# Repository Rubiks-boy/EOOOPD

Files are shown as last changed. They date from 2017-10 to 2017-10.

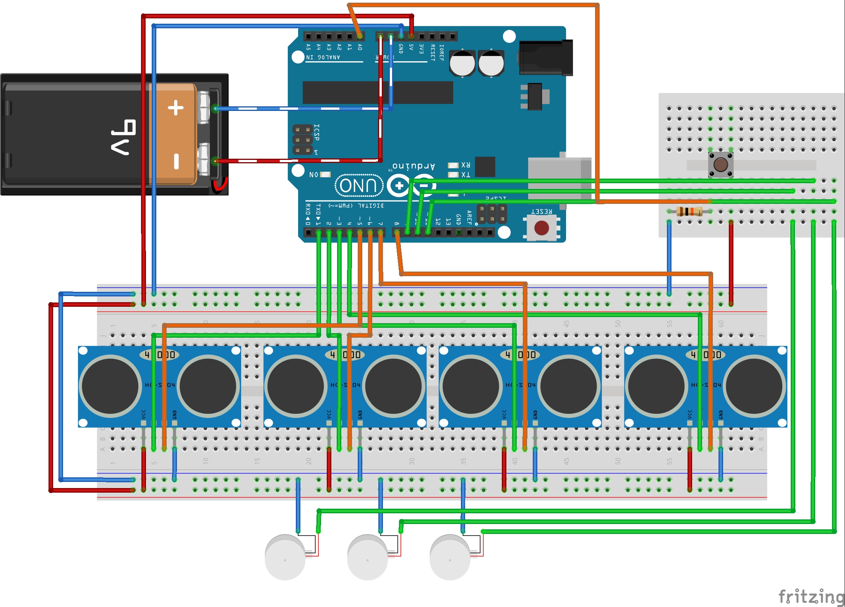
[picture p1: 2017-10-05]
Graphics/breadboard graphic.jpg

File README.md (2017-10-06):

# EOOOPD
Economical Optimal Optical Obstacle Proximity Detector - ISEF Project by Adam Walker &amp; Russell Ro

Embedded system attachment to a white cane; uses ultrasonic sensors on left and right of white cane to detect oncoming obstacles, then warns the user through haptic feedback on the handle via corresponding left and right vibration motors.

Abstract:

The white cane has helped the blind for centuries, but how can this basic invention be revolutionized using twenty-first century technologies at an affordable price? This project tackles the main problem with a white cane: the lack of sideways perception. Distance sensors were added to a standard white cane at angles both left and right, and user feedback is given through vibration sensors. The effectiveness of the sensors was tested by moving objects towards the individual at several velocities and at several angles (left and right). Tests were completed by recording the distance at which user reaction occurred. Our hypothesis was that those who are sight-impaired can sense and avoid objects approaching from increased angles, emulating peripheral vision. The experimental results support this hypothesis by showing that an increased peripheral perception can be achieved through intensifying vibration feedback based on the proximity of an object.

This project won first place in the engineering category at the Beal Bank USA Southern Nevada Regional Science & Engineering Fair at the University of Nevada, Las Vegas on March 15, 2017, qualifying the project for Intel's International Science and Engineering Fair in Los Angeles on May 14-19, 2017.

Adam Walker - adamwalker567123@gmail.com (Programming)<br />
Russell Ro - pr.russell.ro@gmail.com (3D Modeling)

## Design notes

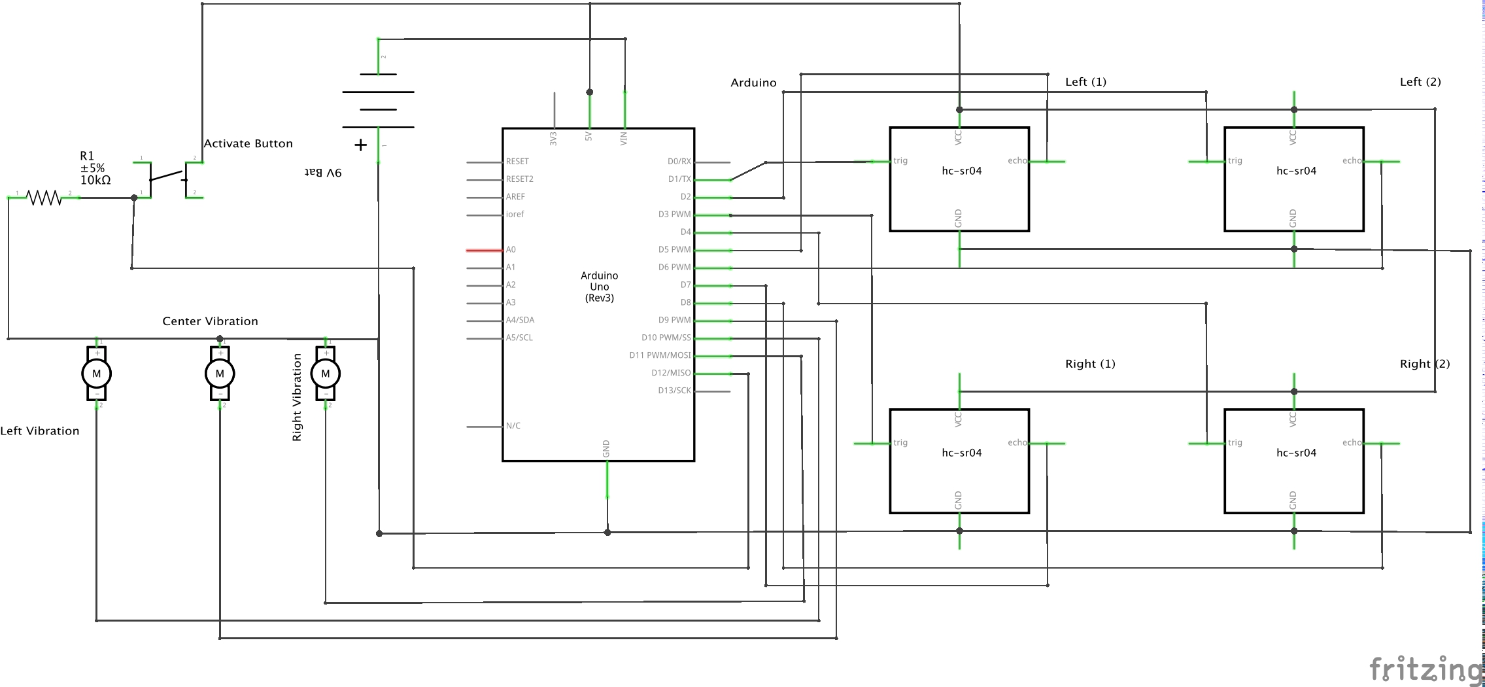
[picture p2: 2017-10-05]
Graphics/schematic.jpg

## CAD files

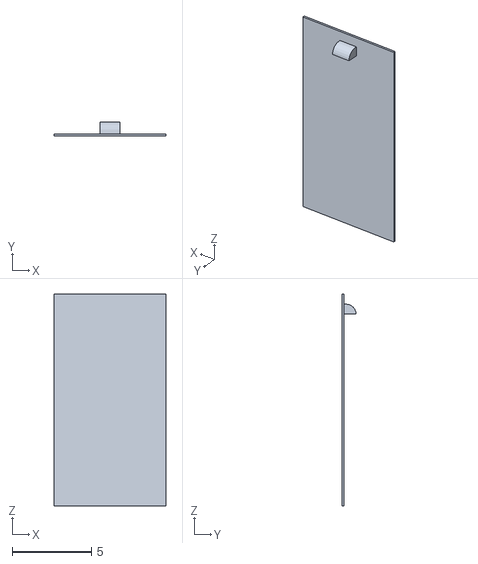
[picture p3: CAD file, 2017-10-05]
Finalized 3D Print Files/EOOOPD Lid V4.stl
7.03 x 0.89 x 13.3

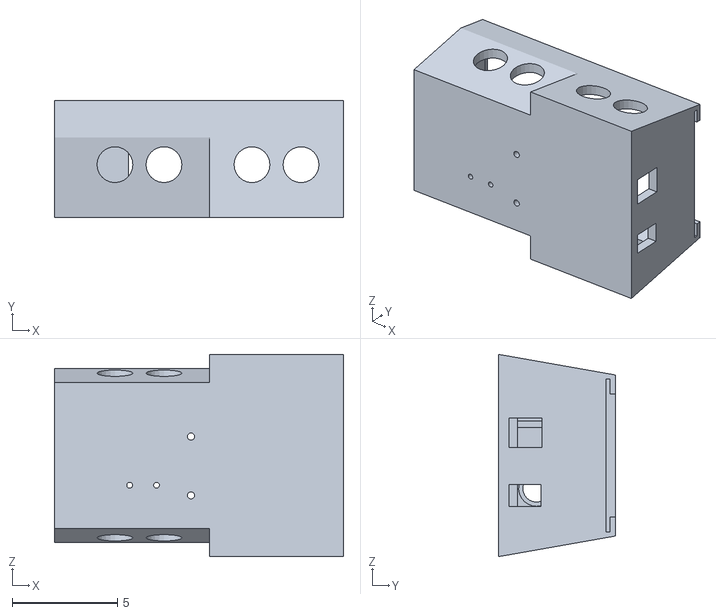
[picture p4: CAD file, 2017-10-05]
Finalized 3D Print Files/EOOOPD Casing V4.stl
13.7 x 5.54 x 9.59

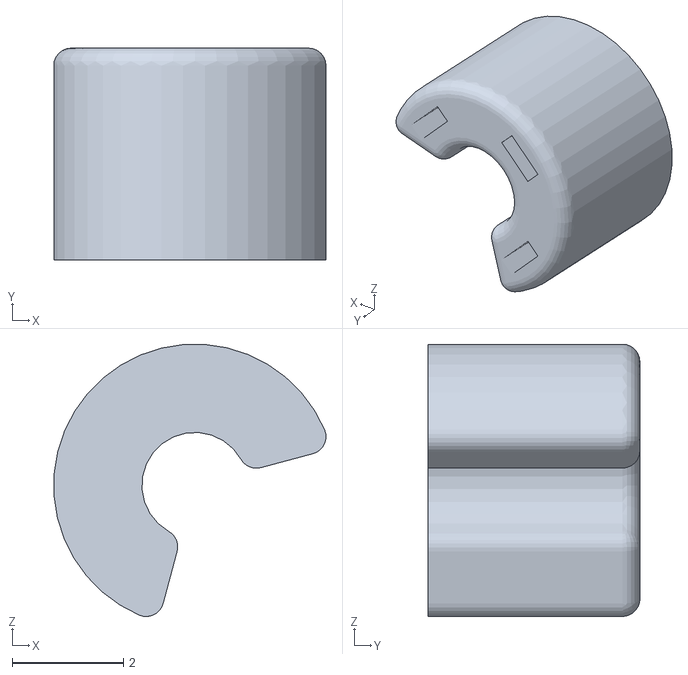
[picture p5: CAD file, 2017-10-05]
Finalized 3D Print Files/EOOOPD Vibration Encasement V3.stl
4.89 x 3.81 x 4.89

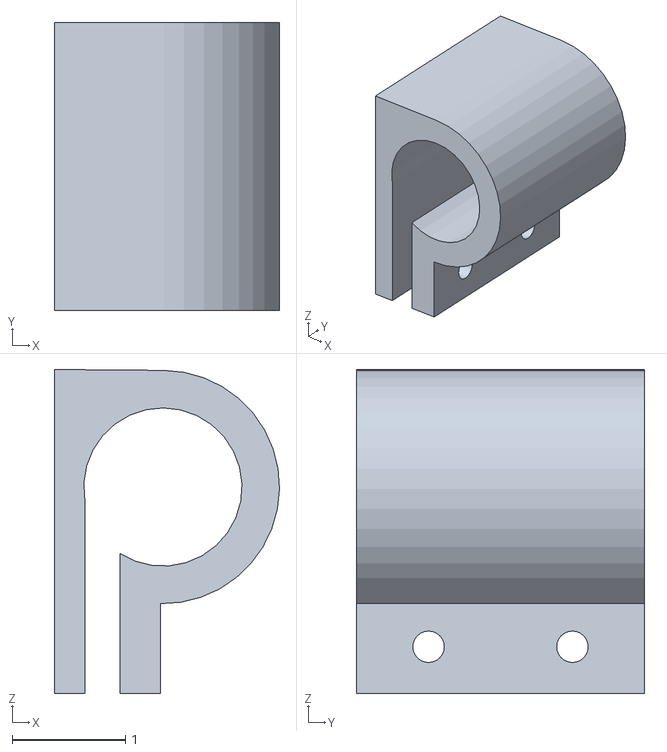
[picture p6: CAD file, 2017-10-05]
Finalized 3D Print Files/EOOOPD Clamp V3.stl
1.99 x 2.54 x 2.86

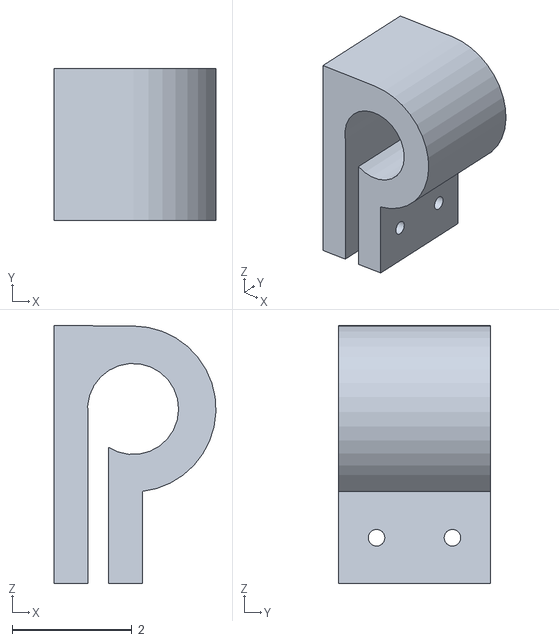
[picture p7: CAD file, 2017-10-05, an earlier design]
Older 3D Print Files/EOOOPD Clamp V1.stl
2.71 x 2.54 x 4.32

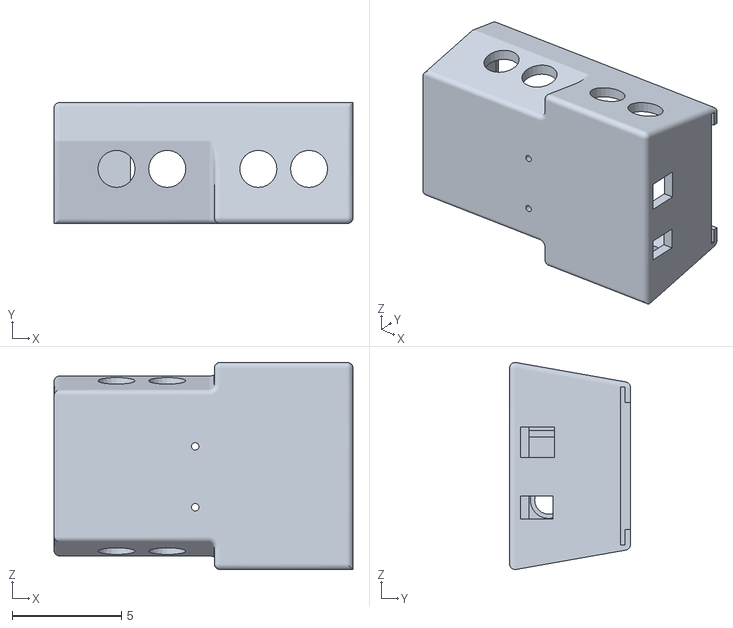
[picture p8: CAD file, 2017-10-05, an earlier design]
Older 3D Print Files/EOOOPD Casing V3 - Filleted.stl
13.7 x 5.54 x 9.49

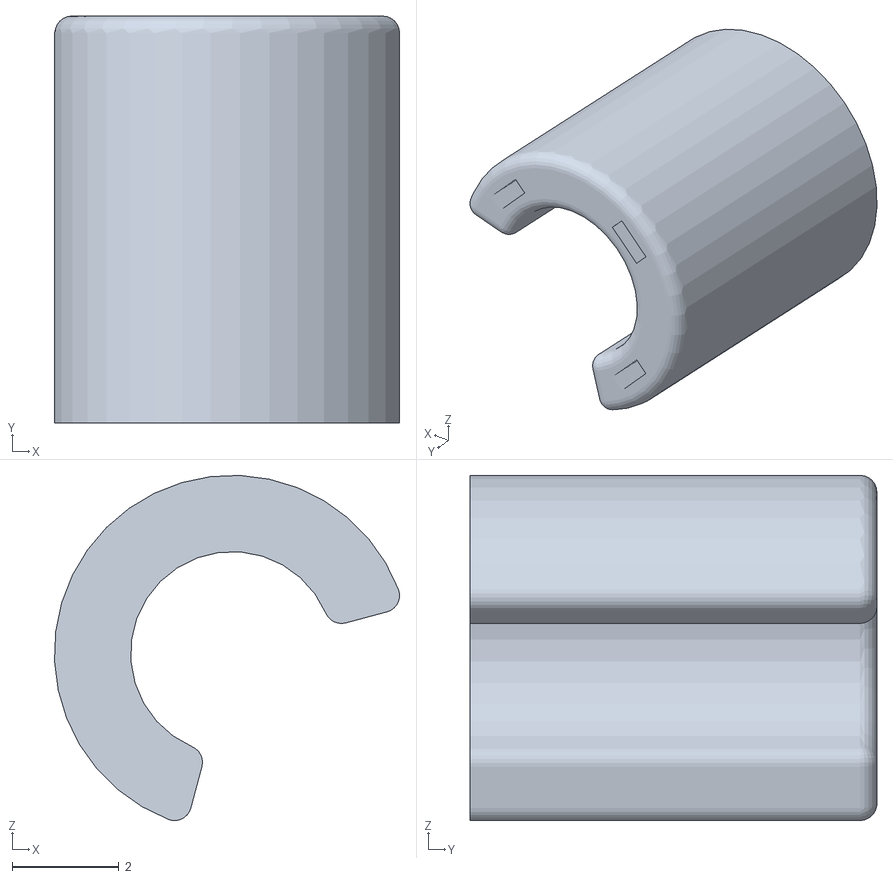
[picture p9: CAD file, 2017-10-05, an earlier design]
Older 3D Print Files/EOOOPD Vibration Encasement V2.stl
6.46 x 7.62 x 6.46

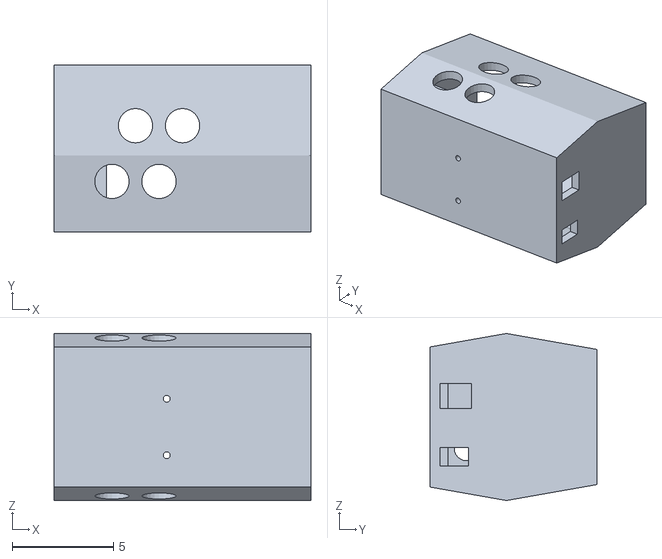
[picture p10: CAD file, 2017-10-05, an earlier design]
Older 3D Print Files/EOOOPD Casing.stl
12.7 x 8.26 x 8.26

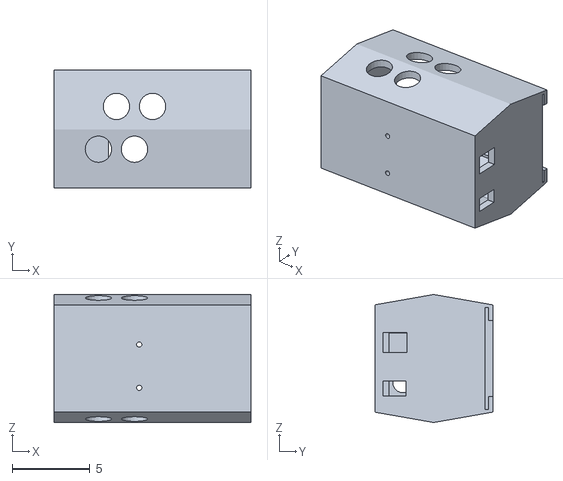
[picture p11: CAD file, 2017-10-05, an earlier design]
Older 3D Print Files/EOOOPD Casing V2.stl
12.7 x 7.60 x 8.26

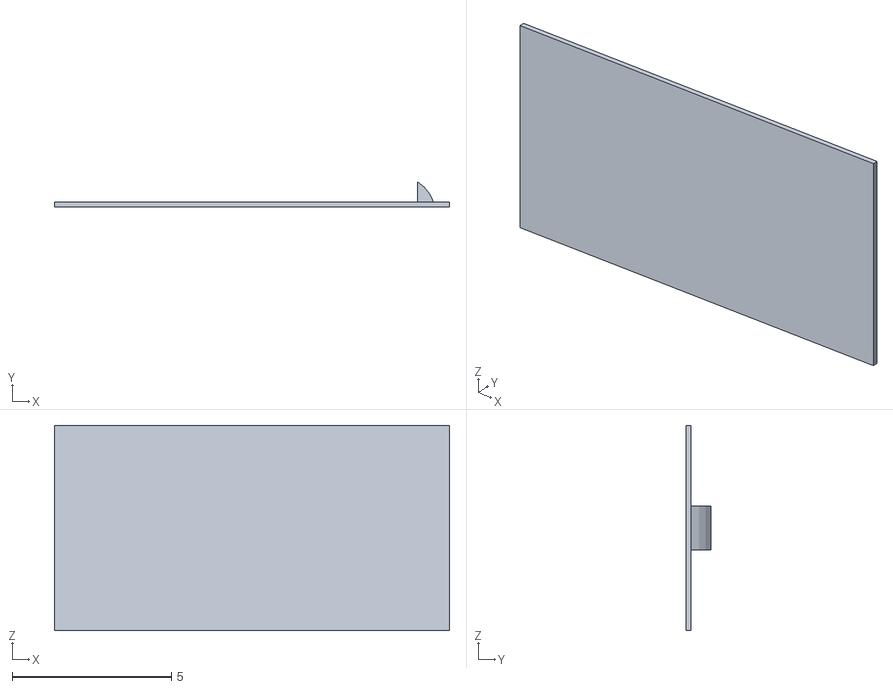
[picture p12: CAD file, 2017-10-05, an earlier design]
Older 3D Print Files/EOOOPD Lid V3 - 0.2 mm.stl
12.4 x 0.795 x 6.45

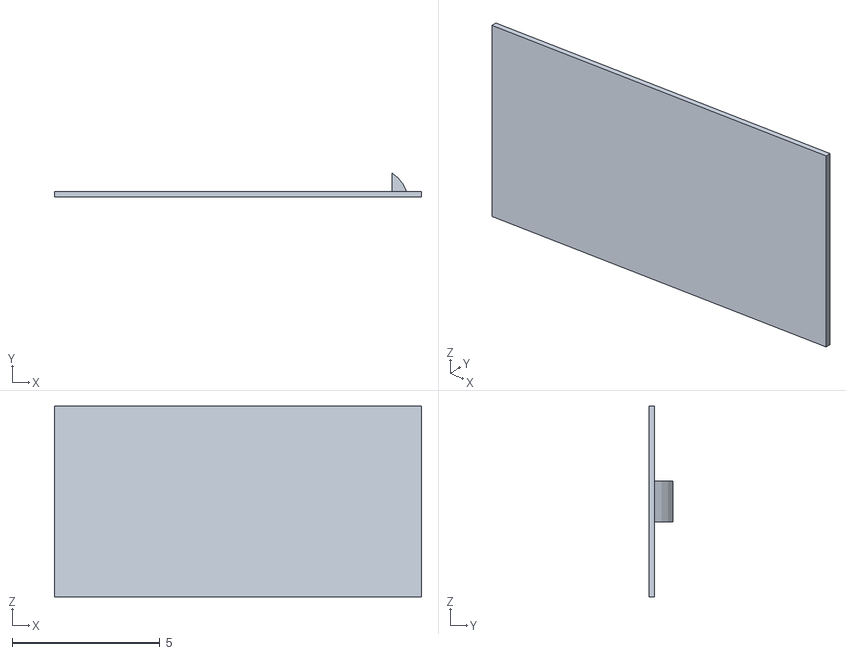
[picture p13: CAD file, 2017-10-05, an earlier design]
Older 3D Print Files/EOOOPD Lid V2.stl
12.4 x 0.815 x 6.45

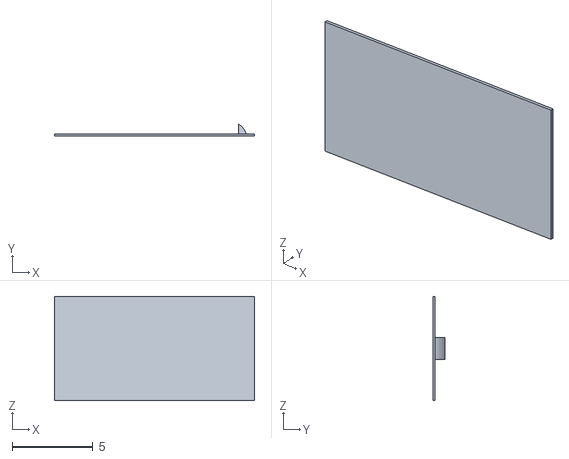
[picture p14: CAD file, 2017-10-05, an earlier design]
Older 3D Print Files/EOOOPD Lid V3 - 0.4 mm.stl
12.4 x 0.775 x 6.45

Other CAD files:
Older 3D Print Files/EOOOPD Clamp V2.stl
Older 3D Print Files/EOOOPD Casing V3.stl

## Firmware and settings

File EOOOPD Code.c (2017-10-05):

const int TRIG1 = 1; //first trigger sensor (second will be TRIG1 + 1, third TRIG+2, etc)
const int SENSOR1 = 5; //first input from the sensor
const int L_VIBRATION = 10; //vibration motor pin on the left
const int R_VIBRATION = 11; //vibration motor pin on the right
const int C_VIBRATION = 9; //vibration motor pin on the center
const int NUM_SENS = 4; //how many sensors
const int TO_CM = 58;  //convert pulse length to CM distance
const int TO_IN = 148;  //convert pulse length to IN distance
const int DELAY_TRIES = 10;  //how much to delay between tries on the same sensor
const int DELAY_SENSORS = 10; //how much to delay between two sensors
const int NUM_TRIES = 1; //how many tries to do each sensor for
const int ACTIVATE_BTN = 12; //button to start vibrations
const int MAX_DIST = 150; //maximum distance read in cm
const int MIN_DIST = 50; //minimum distance read in cm
const int MAX_SENSOR_CHANGE = 23200; //maximum value the sensor can read
const int MAX_DIFF_SENS = 250; //sensors should not read beyond a difference of this
const int MAX_SENS_WRITE = 255; //maximum amount sent to the motor
const double C_MOTOR_COEFF = 1; //how much above 255 the readings can be mapped to. leftover goes to center motor
const boolean DO_OUTPUT = false;

//last readings to calculate the difference between this reading and the last readings
unsigned long lastDiffs[NUM_SENS] = {0, 0, 0, 0};
//new reading from each sensor
unsigned long aveDiffs[NUM_SENS] = {0, 0, 0, 0};
//last iteration button state
boolean lastBtn = LOW;

void setup()
{
  //set up the trigger pins as outputs
  for (int i = TRIG1; i < TRIG1 + NUM_SENS; i++)
  {
    pinMode(i, OUTPUT);
  }
  //set up the sensor pins as inputs
  for (int i = SENSOR1; i < SENSOR1 + NUM_SENS; i++)
  {
    pinMode(i, INPUT);
  }

  //begin serial communciations
  if(DO_OUTPUT)
    Serial.begin(9600);

  //vibration motors are outputs
  pinMode(L_VIBRATION, OUTPUT);
  pinMode(R_VIBRATION, OUTPUT);
  pinMode(C_VIBRATION, OUTPUT);
  
  //button is an input
  pinMode(ACTIVATE_BTN, INPUT);
}

void loop()
{
  //read the sensors
  readSensors();
  
  //see if button is pressed
  if (digitalRead(ACTIVATE_BTN))
  {
    //vibrate motors
    vibration();
    lastBtn = HIGH;
  }
  else
  {
    if (!lastBtn)
    {
      //button isn't pressed so turn off vibration
      analogWrite(L_VIBRATION , 0);
      analogWrite(R_VIBRATION, 0);
      analogWrite(C_VIBRATION, 0);
    }
    lastBtn = LOW;
  }
  
  //push back current data to last
  setToLast();
}

void readSensors()
{
  //for each sensor
  for (int i = 0; i < NUM_SENS; i++)
  {
    //lengths of each pulse for each try
    unsigned long diffs[NUM_TRIES];

    //for each try
    for (int t = 0; t < NUM_TRIES; t++)
    {
      //before the pulse and after the pulse
      unsigned long beforeTime, afterTime;

      //current pins of the sensors
      int currSens = SENSOR1 + i;
      int currTrig = TRIG1 + i;

      //send pulse to the sensor
      digitalWrite(currTrig, HIGH);
      delayMicroseconds(10);
      digitalWrite(currTrig, LOW);

      //wait for pulse back
      while (digitalRead(currSens) == 0);

      //calculate the length of time of the pulse
      beforeTime = micros();
      while (digitalRead(currSens) == 1);
      afterTime = micros();
      diffs[t] = afterTime - beforeTime;

      //wait to do the next try
      delay(DELAY_TRIES);

      //reread if it's unreasonable
      if (abs((long)diffs[t] - (long)lastDiffs[t]) > MAX_SENSOR_CHANGE)
      {
        if(DO_OUTPUT)
          Serial.println("Error in sensor readings. Using last.");
        diffs[t] = lastDiffs[t];
      }
    }

    //calculate the average of the data set and convert to in and cm
    aveDiffs[i] = calcAve(diffs);
    double in = aveDiffs[i] / (double)TO_IN, cm = aveDiffs[i] / (double)TO_CM;

    if (DO_OUTPUT)
    {
      //output information:
      //which sensor
      Serial.print("Sensor: ");
      Serial.println(i + 1);
      Serial.println("Tries: ");
      //all of the tries
      for (int t = 0; t < NUM_TRIES; t++)
      {
        Serial.print(diffs[t]);
        Serial.print('\t');
      }
      Serial.println();

      //average of the data and distance away
      Serial.print("Average (removing outliers): ");
      Serial.println(aveDiffs[i]);
      Serial.print("Ave IN: ");
      Serial.println(in);
      Serial.print("Ave CM: ");
      Serial.println(cm);
      Serial.print("Difference from last read: ");

      //change from the last set of data
      if ((long)aveDiffs[i] - (long)lastDiffs[i] >= 0)
      {
        Serial.print('+');
        Serial.println((long)aveDiffs[i] - (long)lastDiffs[i]);
      }
      else
      {
        Serial.print('-');
        Serial.println((long)lastDiffs[i] - (long)aveDiffs[i]);
      }
      Serial.println();
    }
    //time to wait between sensors
    delay(DELAY_SENSORS);
  }
}

//push back data currently in current to last
void setToLast()
{
  for (int i = 0; i < NUM_SENS; i++)
  {
    lastDiffs[i] = aveDiffs[i];
  }
}

//convert the average of two current datas at index and index + 1 to centimeter distance
//also make sure both data sensors are reasonable; if not just use one sensor's data.
double toCM(int index)
{
  long d1 = (long)aveDiffs[index];
  long d2 = (long)aveDiffs[index + 1];
  if(abs(d1 - d2) > MAX_DIFF_SENS)
  {
   double aveLast = (lastDiffs[index] + lastDiffs[index + 1] ) / 2.0; 
   
   if((abs(d1 - aveLast) > MAX_SENSOR_CHANGE) && abs(d1 - aveLast) < MAX_SENSOR_CHANGE)
     return d2;
   else if(abs(d2 - aveLast) > MAX_SENSOR_CHANGE && abs(d1 - aveLast) < MAX_SENSOR_CHANGE)
     return d1;
  }
  double ave = (d1 + d2) / 2.0;
  return ave / (double)TO_CM;
}

//calculate intensity of PWM vibration and send it to the motors
void vibration()
{
  //get distances
  double cmL = toCM(0);
  double cmR = toCM(2);
  
  //make sure it isn't too big or too small of a distance
  if(cmL < MIN_DIST)
    cmL = MIN_DIST;
  if(cmR < MIN_DIST)
    cmR = MIN_DIST;
  if(cmR > MAX_DIST)
    cmR = MAX_DIST;
  if(cmL > MAX_DIST)
    cmL = MAX_DIST;
   
  //map the distance to an intensity, linearly
  int lMotor = map(cmL, MAX_DIST, MIN_DIST, 0, MAX_SENS_WRITE * C_MOTOR_COEFF);
  int rMotor = map(cmR, MAX_DIST, MIN_DIST, 0, MAX_SENS_WRITE * C_MOTOR_COEFF);

  //set up center motor to take the overflow over 255
  int cMotor = 0;
  if (lMotor > MAX_SENS_WRITE)
  {
    cMotor += lMotor - MAX_SENS_WRITE;
    lMotor = MAX_SENS_WRITE;
  }
  if (rMotor > MAX_SENS_WRITE)
  {
    cMotor += rMotor - MAX_SENS_WRITE;
    rMotor = MAX_SENS_WRITE;
  }
  if (cMotor > MAX_SENS_WRITE)
    cMotor = MAX_SENS_WRITE;

  //write the motor intensities
  analogWrite(L_VIBRATION , lMotor);
  analogWrite(R_VIBRATION, rMotor);
  analogWrite(C_VIBRATION, cMotor);
  
  //output the intensities
  if(DO_OUTPUT)
  {
  Serial.print(lMotor);
  Serial.print('\t');
  Serial.print(rMotor);
  Serial.print('\t');
  Serial.println(cMotor);
  }
}

//calculates the average of the data set
unsigned long calcAve(unsigned long diffs[])
{
  unsigned long sum;
  sum = diffs[0];

  //find the greatest and least in the data set.
  //add all to get the sum.
  for (int t = 1; t < NUM_TRIES; t++)
  {
    sum += diffs[t];
  }

  //return average
  return sum / (double)(NUM_TRIES);
}

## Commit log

2017-10-05 Added Relevant Files
    Added 3d printing revisions, finalized print files, code, and schematic/breadboard graphics.
    [EOOOPD Casing V2.stl, EOOOPD Casing V3 - Filleted.stl, EOOOPD Casing V3.stl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]
2017-10-05 Added Relevant Files
    [breadboard.fzz]
